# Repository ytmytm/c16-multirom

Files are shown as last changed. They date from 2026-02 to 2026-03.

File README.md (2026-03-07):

# C16 multirom




This project is a **multirom board for the Commodore 16 only**. It is heavily inspired by the [ROM update for Commodore 16](https://myoldcomputer.nl/other-computers/commodore-16/rom-update-commodore-16/) at My Old Computer.

The stock C16 uses **two separate chips** for BASIC and KERNAL. By putting **BASIC and KERNAL in a single 64K chip** (U3), we free the second socket for a **function ROM** (U4) e.g. 3-plus-1 and [Parobek](https://github.com/ytmytm/plus4-parobek), so the C16 gains capabilities similar to the Plus/4. Replacing the original mask ROMs with EEPROMs (e.g. 27E512) also reduces power draw.

**ROM switching**: each 64K chip holds two 32K images selected by address line A15. You can fix the choice with **switches** or **jumpers** on J1/J2 (closed = lower half, open = upper half), or add the optional **ATtiny85** to cycle through the four combinations with a long press on RESET.

## What you get

- **U3 (system ROM)**: One 64K chip with BASIC (same in both halves) and two kernals—e.g. stock in the lower 32K and JiffyDOS or 6510-patched in the upper 32K
- **U4 (function ROM)**: One 64K chip with **3-plus-1** in the lower 32K and **Parobek** in the upper 32K
- **Optional ATtiny85**: long-press RESET cycles U3 and U4 A15 through 00, 01, 10, 11 so you can change ROM set without opening the case or drilling holes for switches

## Hardware

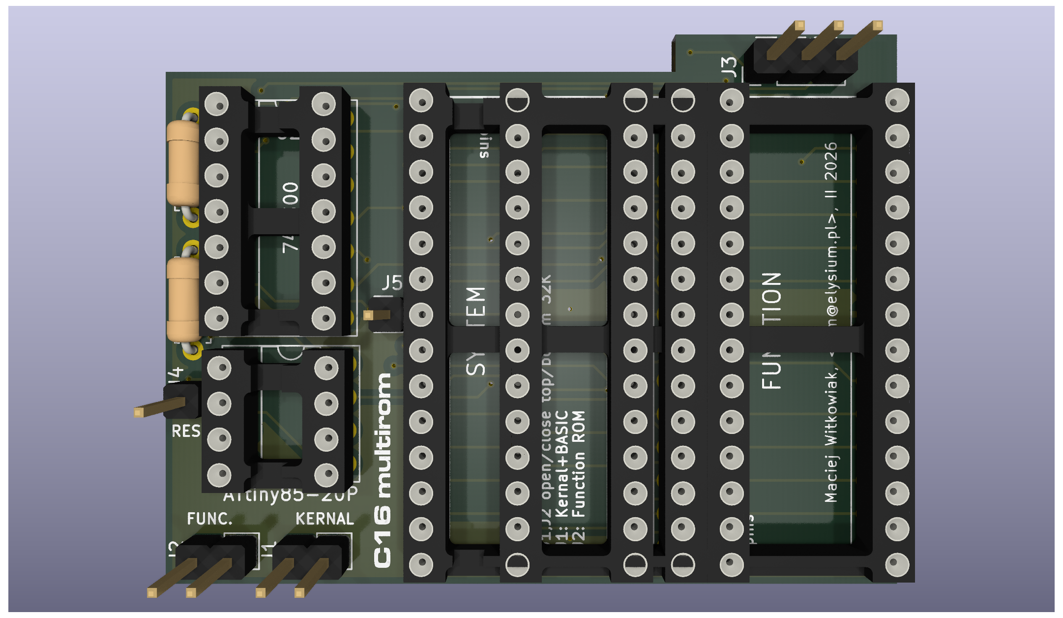
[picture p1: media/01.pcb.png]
Board


The board is designed for the **C16** only. It plugs into the original ROM sockets (system and function) and uses:

- **U3**: 27C512 / 27E512 (64K) — system ROM (BASIC + two kernals in one chip).
- **U4**: 27C512 / 27E512 (64K) — function ROM (3-plus-1 + Parobek).
- **Glue logic**: 74LS00 (or HC/HCT).
- **Optional**: ATtiny85-20P for RESET long-press bank switching.

Precision pin headers plug into the existing socket footprints. Jumpers J1 and J2 set A15 on U3 and U4 to choose the active 32K half; you can wire switches to J1/J2 instead, or let the ATtiny control them.

### BOM

- 2× 28-pin DIP socket (for 27C512/27E512)
- 1× 8-pin DIP socket (for ATtiny85, if used)
- 1× 74LS00 or 74HCT00
- 2× 10K resistors
- 2× 2-pin pinheaders (J1, J2 — ROM half select)
- 2x14 + 1x1 - precision pinheaders (round gold pins) for mainboard socket connection
- 2× 27C512 or 27E512 (64K EPROM/EEPROM)
- 1× ATtiny85-20P (optional, for long-press bank switch)

### Assembly

1. Solder the precision pin headers so the board mates with the original ROM sockets (U3 and U4 positions on the C16 mainboard). Check orientation.
2. Solder resistors, 74LS00, and sockets. If using the ATtiny, program it with the firmware in `attiny/` and fit it. **Note:** The ATtiny firmware is untested.
3. Burn the two 64K ROM images to the EPROMs (see **ROM images** below). Put the system ROM in the new U3 and the function ROM in the new U4 (note that their positions are reversed when compared to the mainboard).
4. Set J1 and J2 (or leave them open for default halves). Power on and test.

**Note on PLA replacements:** If you use PLA replacements (daughterboards with GAL or CPLD) that are wider than a 28-pin DIL chip, the extra width can make the multirom board a tight fit. After soldering the sockets—but before plugging in any chips—you may want to use sandpaper to remove some material from the right-hand edge of the PCB so it fits better.

There are no traces on that side; you can cut right up to the actual pins of the new U4 socket, leaving them open like half-circles.

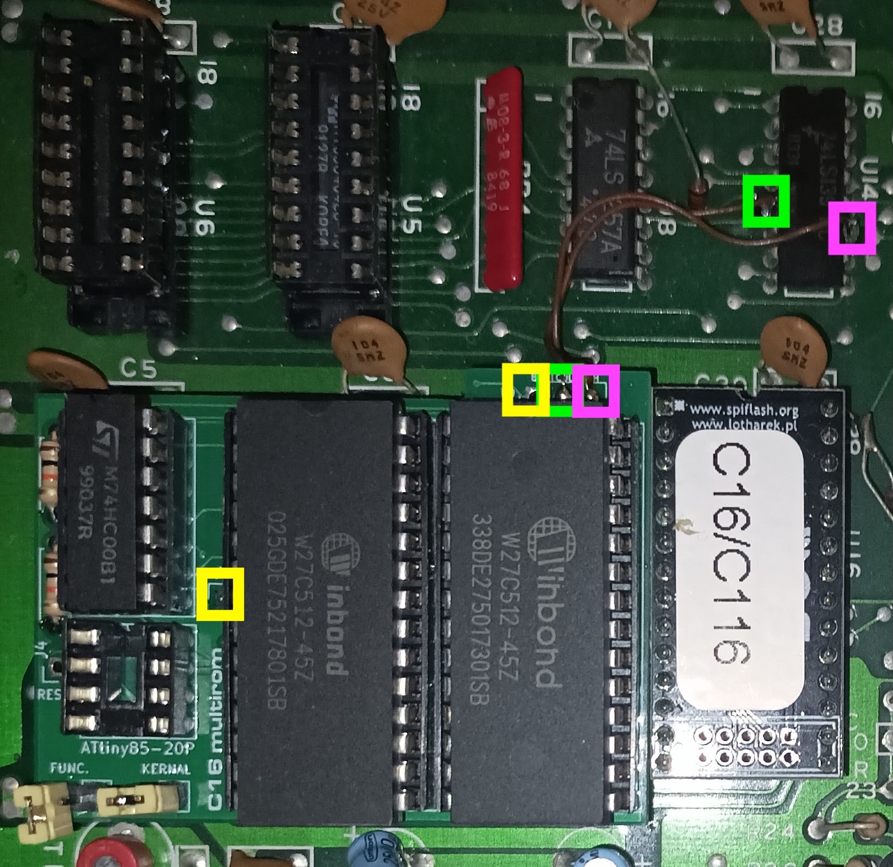
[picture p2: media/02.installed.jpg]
C16 multirom board installed in mainboard


*In the photo: the yellow square marks the /BASIC line, which is not connected on J3 because J5 takes it from the mainboard socket (U3 pin 22). The green and purple rectangles show how the J3 /C0LOW and /C0HIGH lines are taken from U14 pins 5 and 11.*

## Project files (KiCad)

- [KiCad project](kicad-c16-multirom/)
- [Schematic PDF](kicad-c16-multirom/plots/kicad-c16-multirom.pdf)
- [Gerbers](kicad-c16-multirom/gerbers/) (or use the packaged zip in that folder for JLCPCB etc.)
  <!-- Order boards: <a href="https://www.pcbway.com/project/shareproject/...">PCBWay</a> -->
- [docs/](docs/) — additional documentation and notes.

## ROM images

The `rom/` directory contains a script and Makefile that build the 64K ROM images from public sources (Zimmers, Parobek, 6510 kernals). Downloads are done once; you choose PAL/NTSC and which kernals go in the lower and upper half of U3.

**Pre-built images** (built from this repo and published in the **Releases** section) are:

- **System ROM (PAL)** — BASIC + stock kernal in lower half, 6510-patched kernal in upper half. For U3; use when J1 is closed = stock, open = 6510.
- **System ROM (NTSC)** — Same layout for NTSC.
- **Function ROM** — 3-plus-1 in lower 32K, Parobek in upper 32K. Single image for U4; J2 closed = 3-plus-1, open = Parobek.

So you can burn one system ROM per region (PAL and NTSC) and one function ROM, and use jumpers or the ATtiny to switch.

### Building the ROMs yourself

From the `rom/` directory:

```sh
cd rom
make
```

Interactive mode will ask for TV standard (PAL/NTSC) and which kernal to use for the lower and upper half of U3 (stock, JiffyDOS, or 6510-patched). Default is stock in the lower half and JiffyDOS in the upper; 6510 kernals are downloaded automatically from hackjunk.com. JiffyDOS binaries (not redistributable) go in `rom/sources/jiffydos/`; see `rom/sources/jiffydos/README.txt`.

Non-interactive example (stock lower, JiffyDOS upper, PAL):

```sh
./build.sh --pal --kernal-lower=stock --kernal-upper=jiffydos
```

Outputs are `rom/out/u3-system.rom` and `rom/out/u4-function.rom`.

To build the **release** variants (stock+6510 PAL, stock+6510 NTSC, and the single function ROM):

```sh
make build-ni PAL=1 KERNAL_LOWER=stock KERNAL_UPPER=6510   # PAL system ROM
make build-ni PAL=0 KERNAL_LOWER=stock KERNAL_UPPER=6510   # NTSC system ROM
# Function ROM is always 3-plus-1 + Parobek (one image)
```

Then copy `out/u3-system.rom` and `out/u4-function.rom` to your release assets.

## Related

- [ROM update for Commodore 16](https://myoldcomputer.nl/other-computers/commodore-16/rom-update-commodore-16/) (My Old Computer) — main inspiration for this project.
- [Parobek ROM](https://github.com/ytmytm/plus4-parobek) — Function ROM with fast loader and extras for C16/+4; the upper half of U4 on this board holds Parobek.
- [C16 / Plus/4 — 8501 to 6510 CPU conversion](https://hackjunk.com/2017/06/23/commodore-16-plus-4-8501-to-6510-cpu-conversion/) — 6510-patched kernals (used in the release ROM builds) come from this project.
- [CBM firmware (Zimmers.net)](https://www.zimmers.net/anonftp/pub/cbm/firmware/computers/plus4/) — Stock BASIC, KERNAL, and 3-plus-1 ROM images; the `rom/` build script downloads from here.

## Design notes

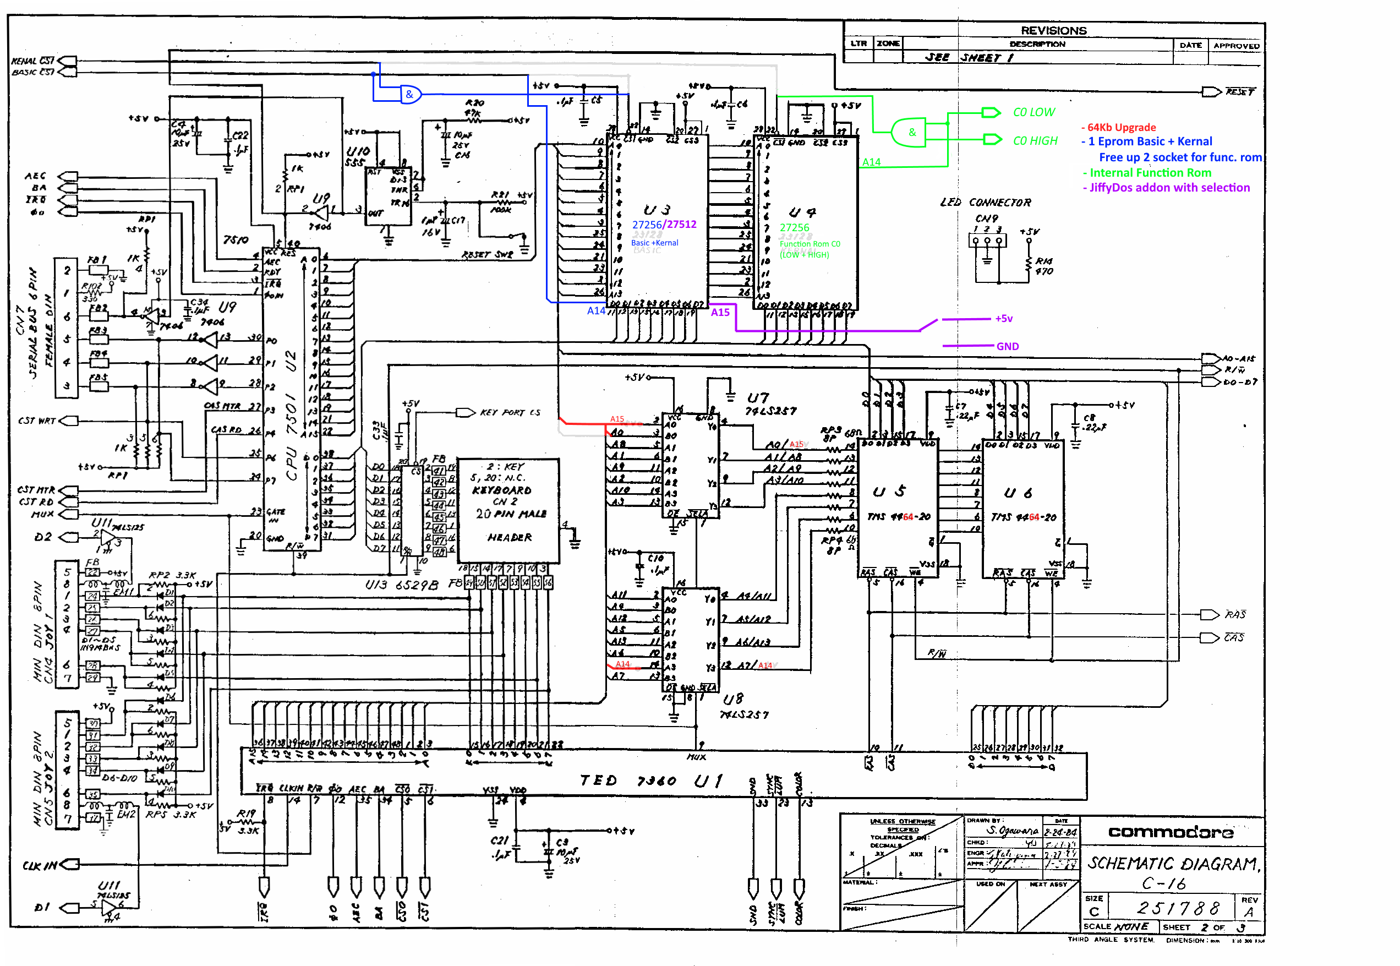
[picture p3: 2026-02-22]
docs/c16-251788-2of3_mods.png

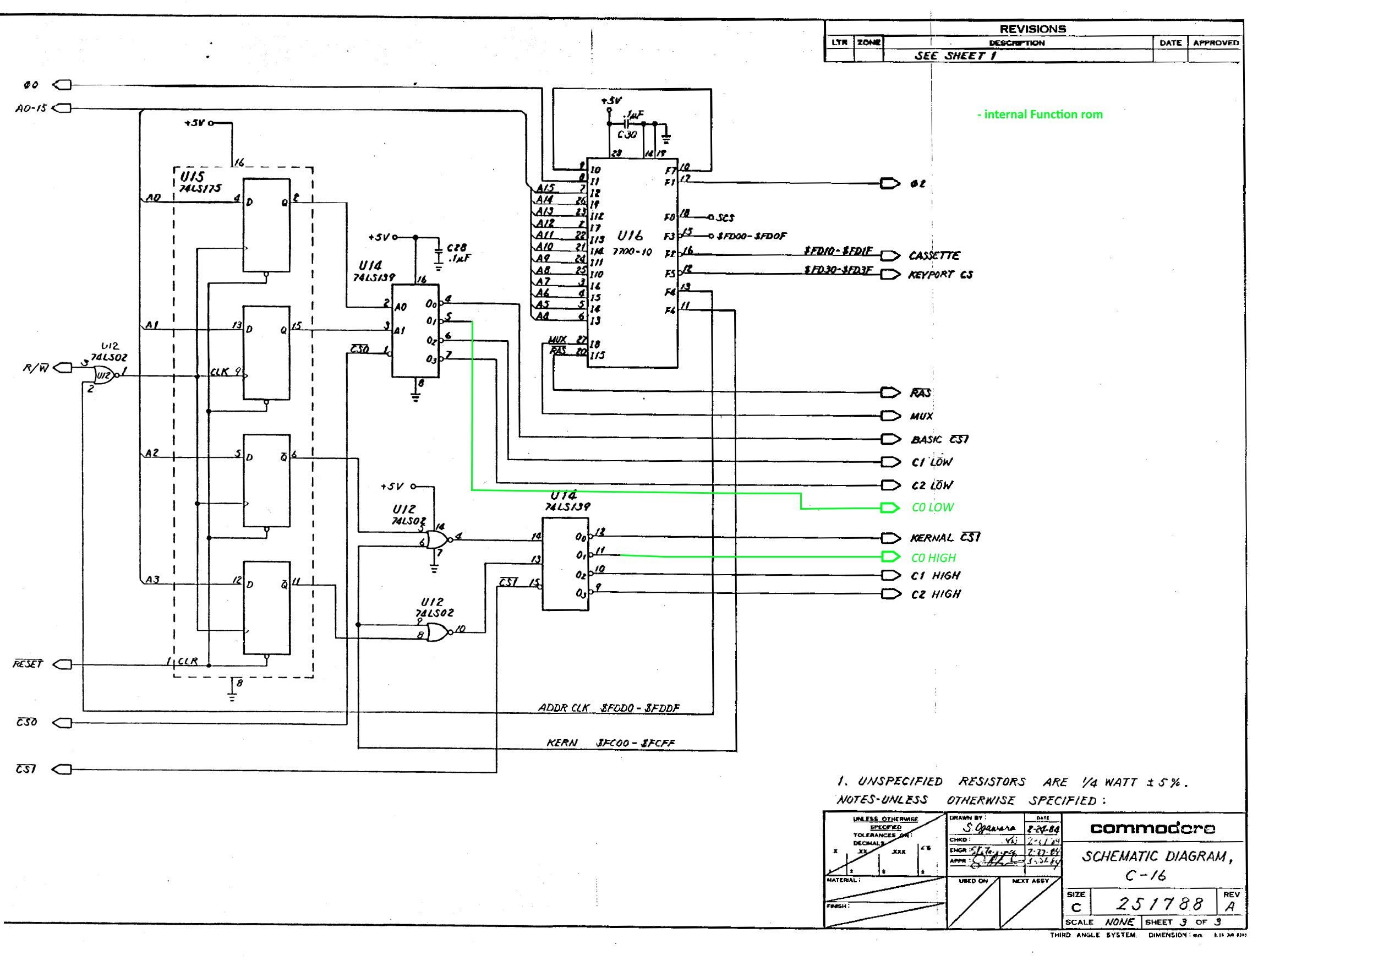
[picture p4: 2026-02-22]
docs/c16-251788-3of3_mods.png

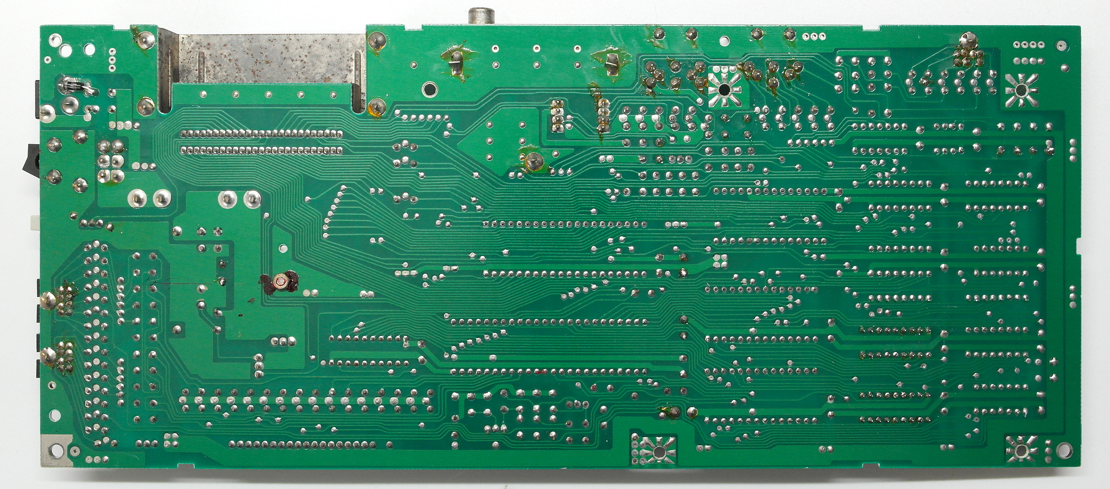
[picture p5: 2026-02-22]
docs/C16_PCBB.jpg

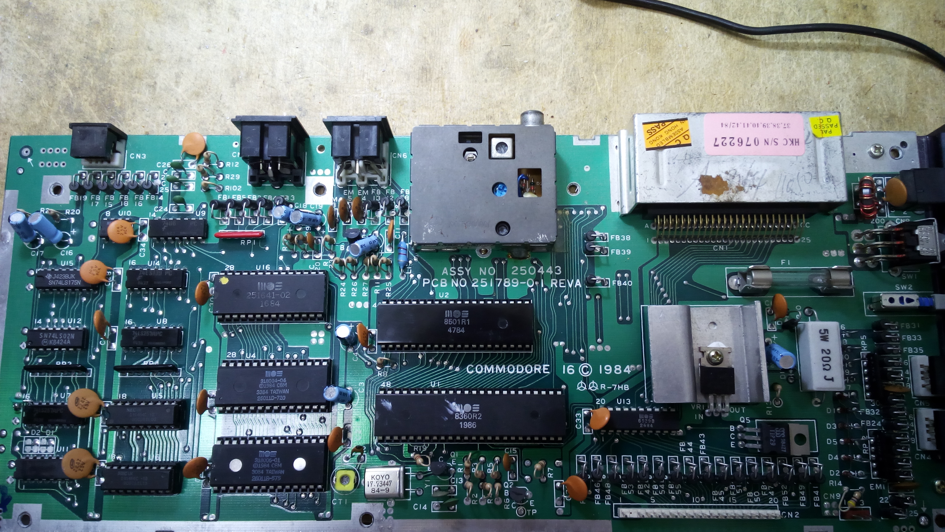
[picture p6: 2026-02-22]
docs/c16.jpg

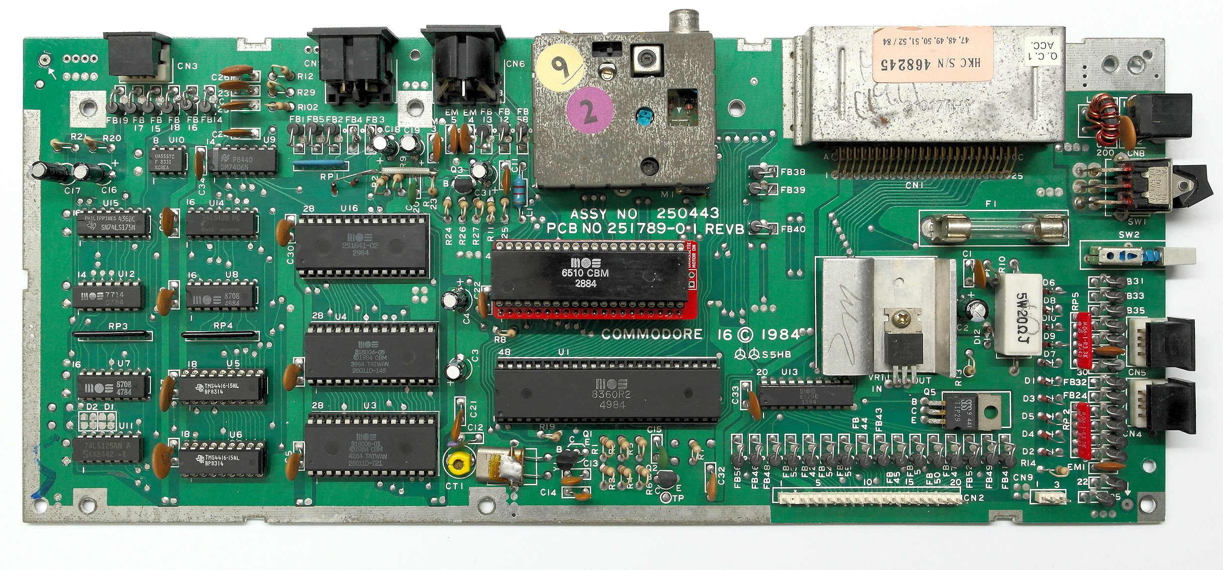
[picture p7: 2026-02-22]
docs/C16_PCBF.jpg

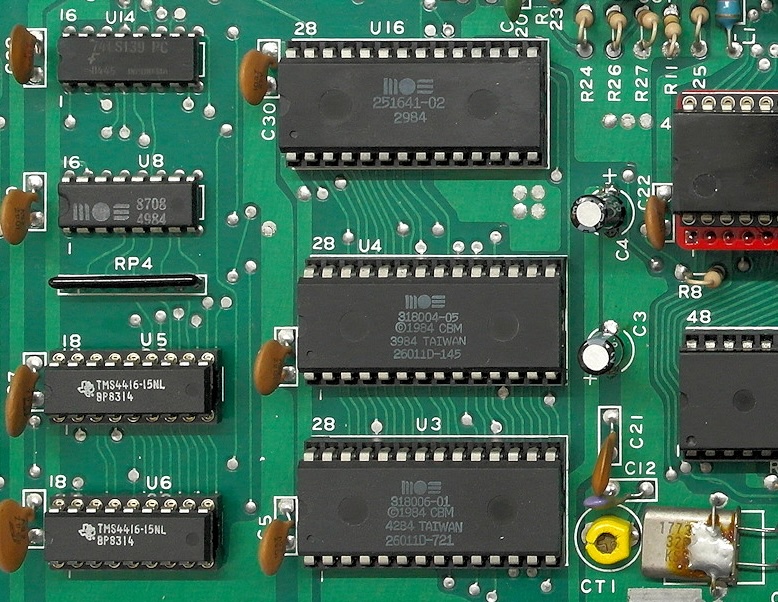
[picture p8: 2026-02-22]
kicad-c16-multirom/c16mobo.jpg

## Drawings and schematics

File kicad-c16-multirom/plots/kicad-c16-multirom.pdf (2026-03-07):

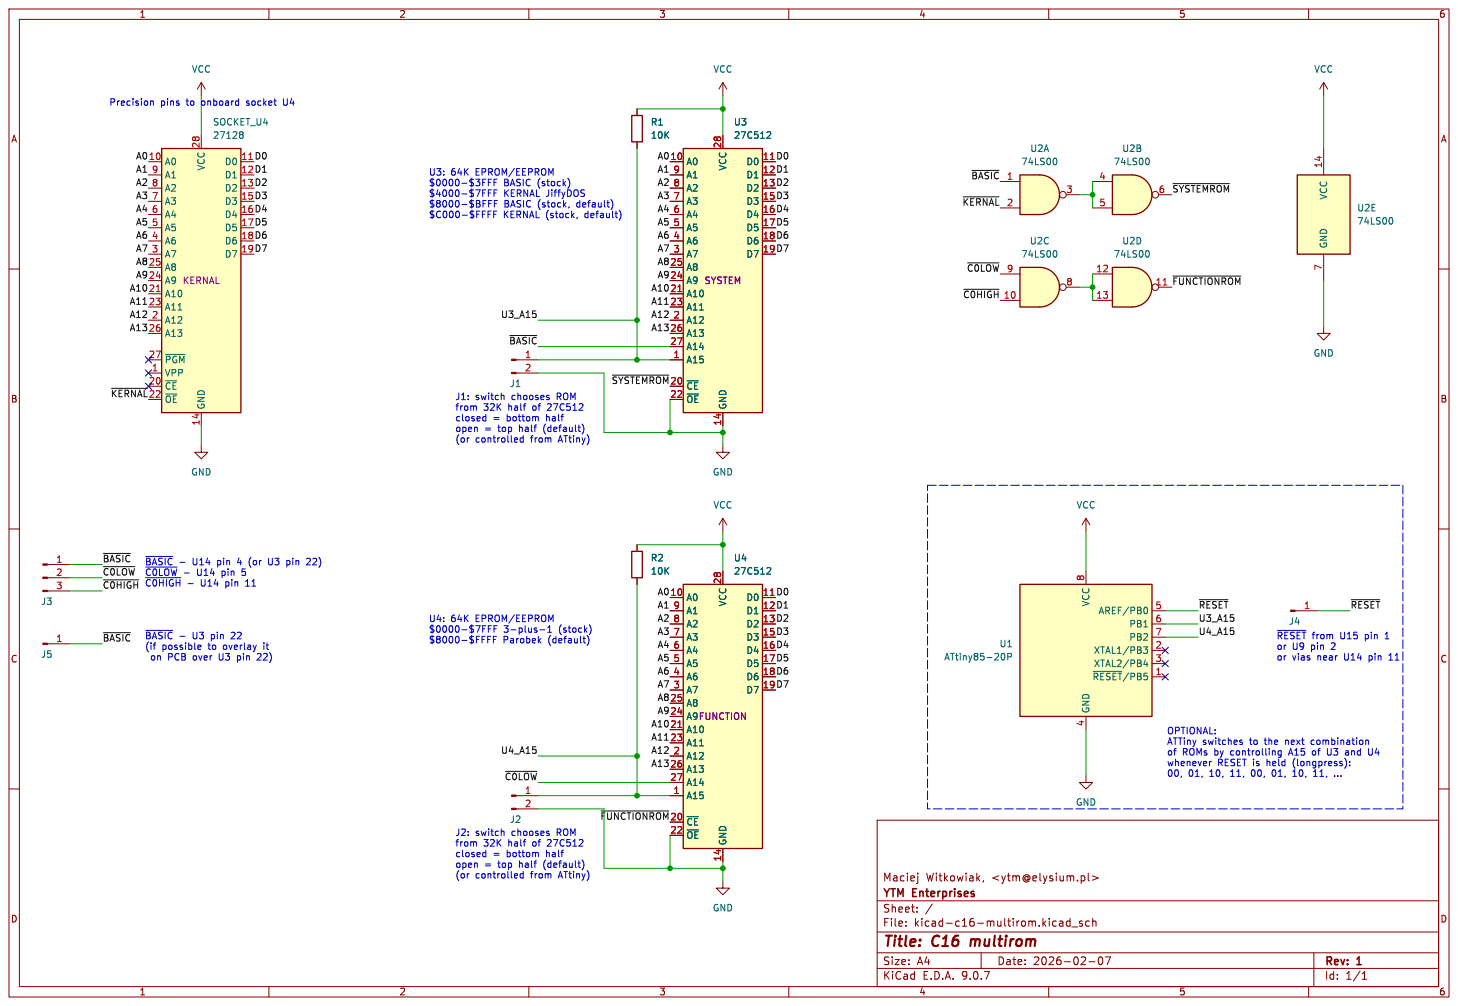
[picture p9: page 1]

J1: switch chooses ROM
from 32K half of 27C512
closed = bottom half open = top half (default)

~{BASIC}- U14 pin 4 (or U3 pin 22)
~{C0LOW}- U14 pin 5 ~{C0HIGH}- U14 pin 11 ~{BASIC}- U3 pin 22

or U9 pin 2
or vias near U14 pin 11

J2: switch chooses ROM

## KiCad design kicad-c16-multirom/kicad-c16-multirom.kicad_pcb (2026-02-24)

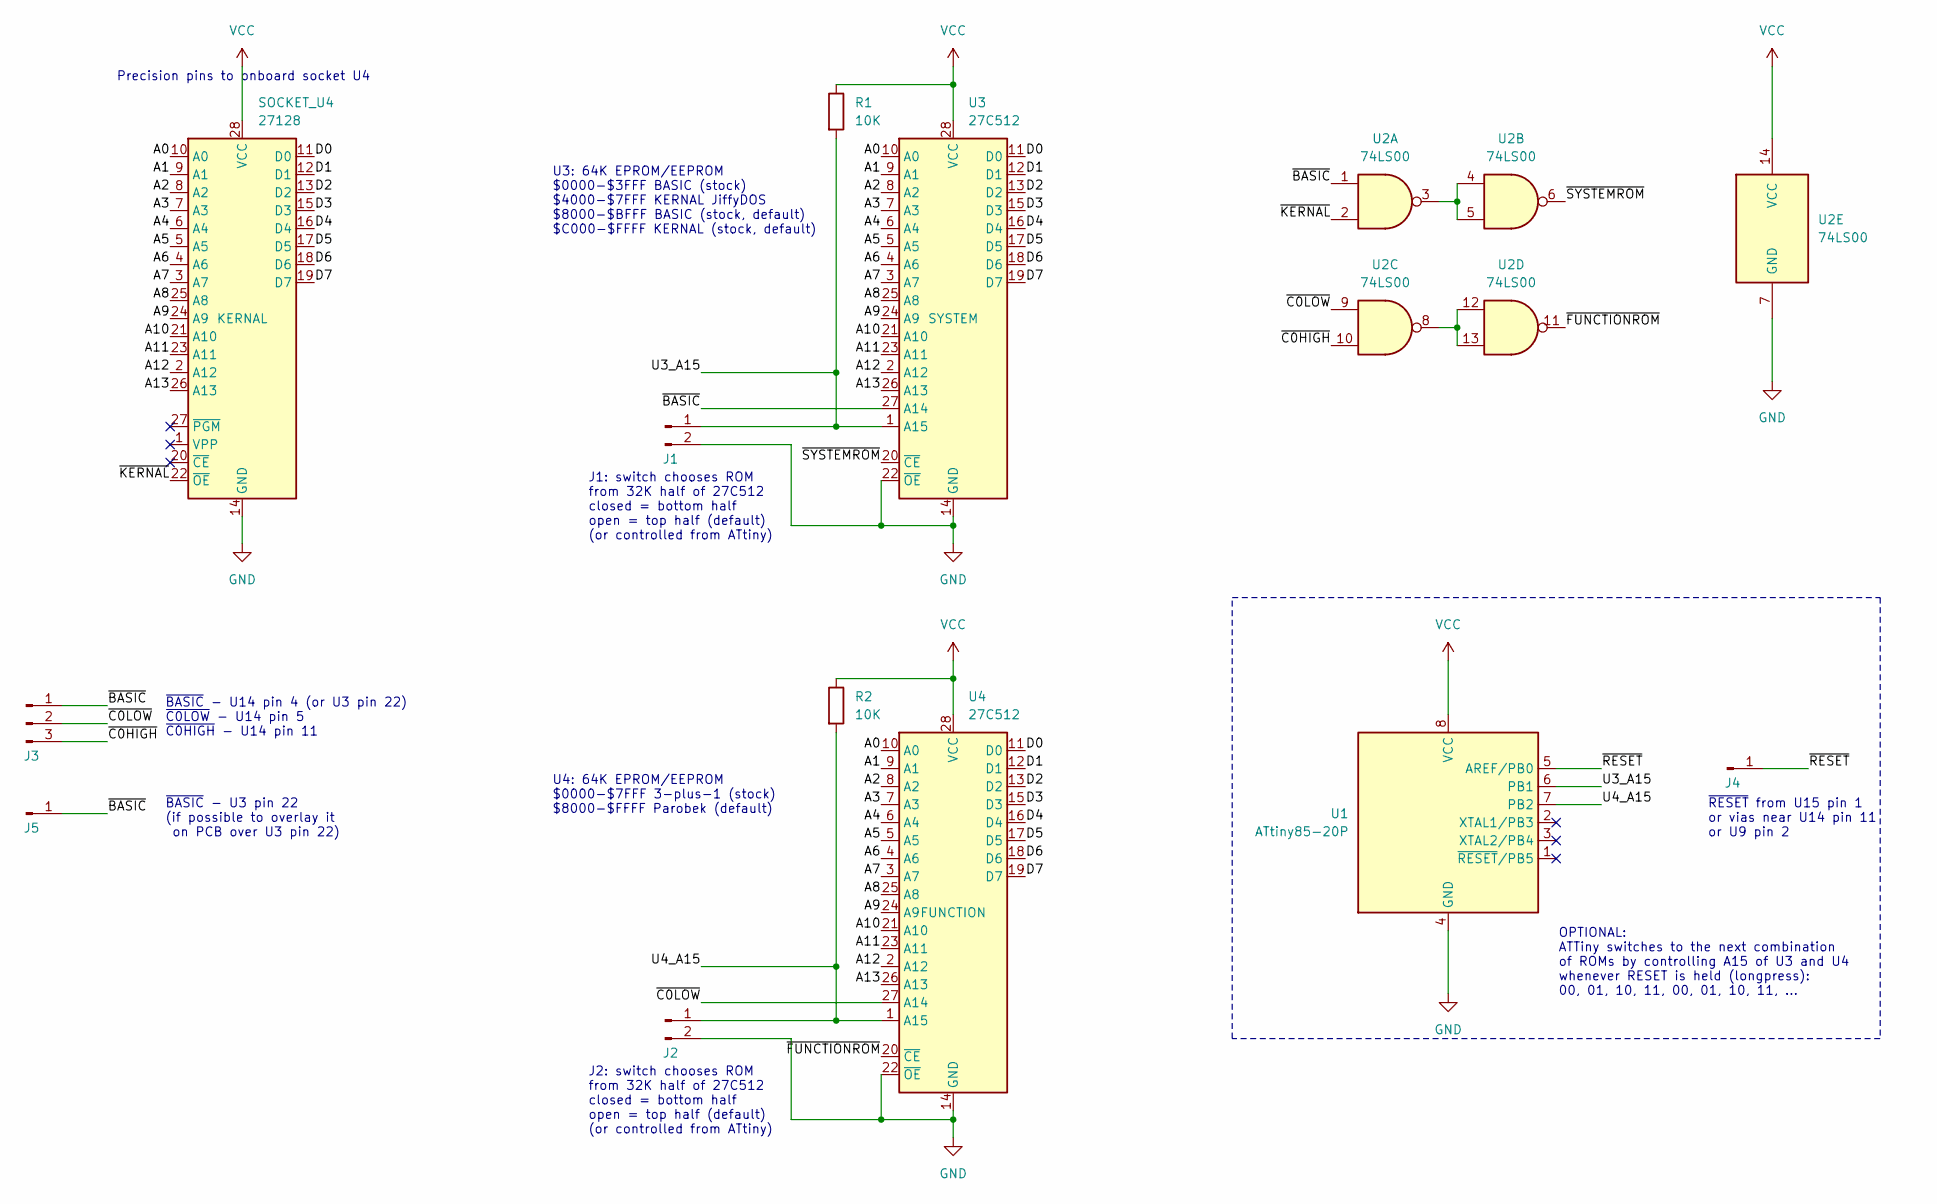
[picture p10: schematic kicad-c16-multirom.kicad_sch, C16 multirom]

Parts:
J1, J2: Conn_01x02_Pin; PinHeader_1x02_P2.54mm_Vertical
J3: Conn_01x01_Pin; PinHeader_1x03_P2.54mm_Vertical
J4, J5: Conn_01x01_Pin; PinHeader_1x01_P2.54mm_Vertical
R1, R2: 10K; R_Axial_DIN0207_L6.3mm_D2.5mm_P7.62mm_Horizontal
SOCKET_U4: 27128; DIP-28_W15.24mm_Socket
U1: ATtiny85-20P; DIP-8_W7.62mm_Socket_LongPads
U2: 74LS00; DIP-14_W7.62mm_Socket_LongPads
U3, U4: 27C512; DIP-28_W15.24mm_Socket_LongPads

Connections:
/A0: SOCKET_U4.10 (A0), U3.10 (A0), U4.10 (A0)
/A1: SOCKET_U4.9 (A1), U3.9 (A1), U4.9 (A1)
/A2: SOCKET_U4.8 (A2), U3.8 (A2), U4.8 (A2)
/A3: SOCKET_U4.7 (A3), U3.7 (A3), U4.7 (A3)
/A4: SOCKET_U4.6 (A4), U3.6 (A4), U4.6 (A4)
/A5: SOCKET_U4.5 (A5), U3.5 (A5), U4.5 (A5)
/A6: SOCKET_U4.4 (A6), U3.4 (A6), U4.4 (A6)
/A7: SOCKET_U4.3 (A7), U3.3 (A7), U4.3 (A7)
/A8: SOCKET_U4.25 (A8), U3.25 (A8), U4.25 (A8)
/A9: SOCKET_U4.24 (A9), U3.24 (A9), U4.24 (A9)
/A10: SOCKET_U4.21 (A10), U3.21 (A10), U4.21 (A10)
/A11: SOCKET_U4.23 (A11), U3.23 (A11), U4.23 (A11)
/A12: SOCKET_U4.2 (A12), U3.2 (A12), U4.2 (A12)
/A13: SOCKET_U4.26 (A13), U3.26 (A13), U4.26 (A13)
/D0: SOCKET_U4.11 (D0), U3.11 (D0), U4.11 (D0)
/D1: SOCKET_U4.12 (D1), U3.12 (D1), U4.12 (D1)
/D2: SOCKET_U4.13 (D2), U3.13 (D2), U4.13 (D2)
/D3: SOCKET_U4.15 (D3), U3.15 (D3), U4.15 (D3)
/D4: SOCKET_U4.16 (D4), U3.16 (D4), U4.16 (D4)
/D5: SOCKET_U4.17 (D5), U3.17 (D5), U4.17 (D5)
/D6: SOCKET_U4.18 (D6), U3.18 (D6), U4.18 (D6)
/D7: SOCKET_U4.19 (D7), U3.19 (D7), U4.19 (D7)
/U3_A15: J1.1, R1.2, U1.6 (PB1), U3.1 (A15)
/U4_A15: J2.1, R2.2, U1.7 (PB2), U4.1 (A15)
/~BASIC: J3.1, J5.1, U2.1, U3.27 (A14)
/~C0HIGH: J3.3, U2.10
/~C0LOW: J3.2, U2.9, U4.27 (A14)
/~FUNCTIONROM: U2.11, U4.20 (~CE)
/~KERNAL: SOCKET_U4.22 (~OE), U2.2
/~RESET: J4.1, U1.5 (AREF/PB0)
/~SYSTEMROM: U2.6, U3.20 (~CE)
GND: J1.2, J2.2, SOCKET_U4.14 (GND), U1.4 (GND), U2.7 (GND), U3.14 (GND), U3.22 (~OE), U4.14 (GND), U4.22 (~OE)
unnamed: U2.3, U2.4, U2.5
unnamed: U2.8, U2.12, U2.13
VCC: R1.1, R2.1, SOCKET_U4.28 (VCC), U1.8 (VCC), U2.14 (VCC), U3.28 (VCC), U4.28 (VCC)

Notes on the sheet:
~{RESET} from U15 pin 1 or vias near U14 pin 11 or U9 pin 2
U3: 64K EPROM/EEPROM $0000-$3FFF BASIC (stock) $4000-$7FFF KERNAL JiffyDOS $8000-$BFFF BASIC (stock, default) $C000-$FFFF KERNAL (stock, default)
U4: 64K EPROM/EEPROM $0000-$7FFF 3-plus-1 (stock) $8000-$FFFF Parobek (default)
Precision pins to onboard socket U4
~{BASIC} - U3 pin 22 (if possible to overlay it on PCB over U3 pin 22)
J2: switch chooses ROM from 32K half of 27C512 closed = bottom half open = top half (default) (or controlled from ATtiny)
J1: switch chooses ROM from 32K half of 27C512 closed = bottom half open = top half (default) (or controlled from ATtiny)
OPTIONAL: ATTiny switches to the next combination of ROMs by controlling A15 of U3 and U4 whenever RESET is held (longpress): 00, 01, 10, 11, 00, 01, 10, 11, ...
~{BASIC} - U14 pin 4 (or U3 pin 22) ~{C0LOW} - U14 pin 5 ~{C0HIGH} - U14 pin 11

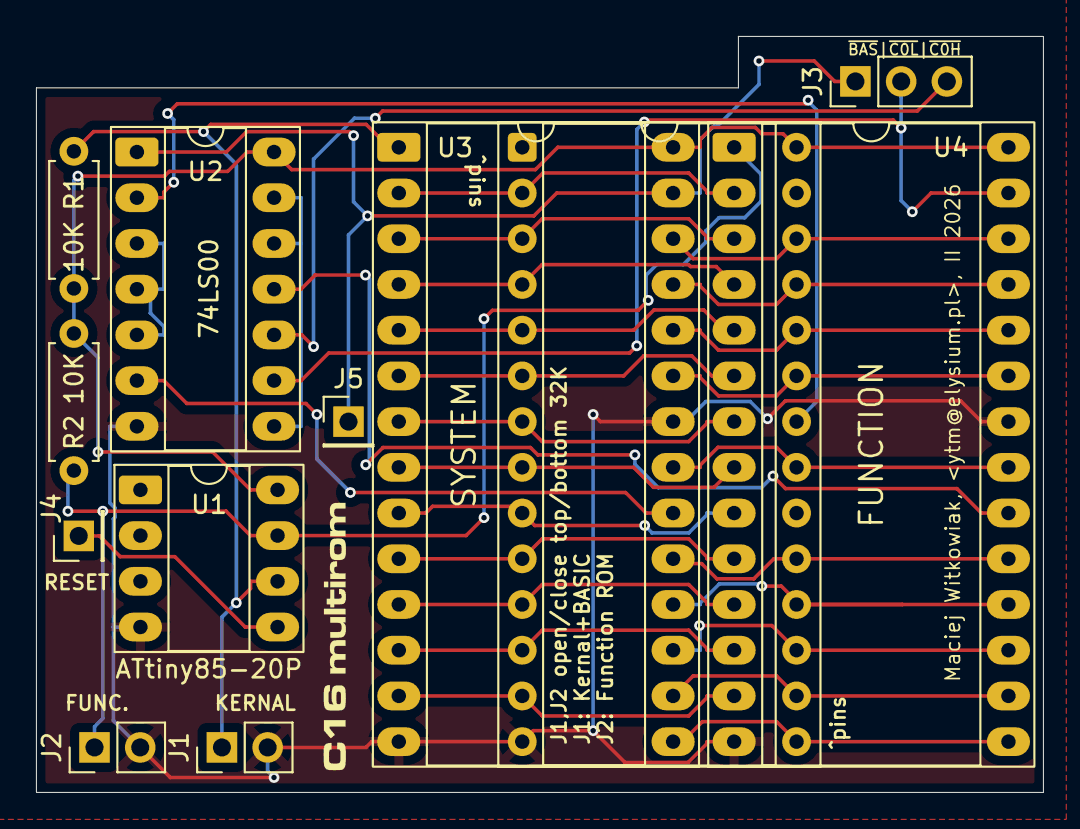
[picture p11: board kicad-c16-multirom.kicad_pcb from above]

Board: 2 copper layers, 55.9 x 42.0 mm, 13 parts (0 on the bottom side), 35 nets.

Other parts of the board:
kibuzzard-6987CFF9: G***; kibuzzard-6987CFF9

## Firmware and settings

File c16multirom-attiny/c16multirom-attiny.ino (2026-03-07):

// IDE: ATtiny25/45/85, internal 1MHz
// 1MHz is the default speed, no need to switch fuses to 8MHz
// compile to HEX (Sketch->Export compiled binary) and burn using TL866-II
//
// ROM bank switcher: detects long presses on system /RESET line,
// cycles through 4 banks (00 -> 01 -> 10 -> 11 -> 00 ...) on two output pins.
// Normal/short resets are ignored. State resets to 00 on every power-on.

// pinout
//   /RESET 1  U  8 VCC
//   A3/PB3 2     7 PB2 --> output: bank address A1 (MSB)
//   A2/PB4 3     6 PB1 --> output: bank address A0 (LSB)
//      GND 4     5 PB0 <-- input: system /RESET (active low)

#define LONG_PRESS_MS  600
#define DEBOUNCE_MS    50

const uint8_t pin_A0    = 1; // PB1, pin 6 -- bank address bit 1
const uint8_t pin_A1    = 2; // PB2, pin 7 -- system /RESET sense
const uint8_t pin_reset = 0; // PB0, pin 5 -- bank address bit 0

uint8_t bank = 0;

static void applyBank() {
  digitalWrite(pin_A0, bank & 1);
  digitalWrite(pin_A1, (bank >> 1) & 1);
}

void setup() {
  pinMode(pin_A0, OUTPUT);
  pinMode(pin_A1, OUTPUT);
  applyBank();

  pinMode(pin_reset, INPUT_PULLUP);

  // Wait for the system to release /RESET after power-on.
  // This avoids treating the power-on reset as a long press.
  while (digitalRead(pin_reset) == LOW)
    ;
  delay(DEBOUNCE_MS);
}

void loop() {
  // Wait for /RESET to be asserted (pulled LOW)
  if (digitalRead(pin_reset) != LOW)
    return;

  delay(DEBOUNCE_MS);
  if (digitalRead(pin_reset) != LOW)
    return;

  // /RESET is confirmed LOW -- start timing
  unsigned long pressed_at = millis();

  while (digitalRead(pin_reset) == LOW) {
    if (millis() - pressed_at >= LONG_PRESS_MS) {
      // Long press detected -- advance bank while system is held in reset
      bank = (bank + 1) & 3;
      applyBank();

      // Wait for button release
      while (digitalRead(pin_reset) == LOW)
        ;
      delay(DEBOUNCE_MS);
      return;
    }
  }
  // /RESET released before threshold -- short press, ignore
  delay(DEBOUNCE_MS);
}

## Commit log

2026-02-24 correct reference image placement, lock footprints for precision pins that go down to the mainboard
    [kicad-c16-multirom.kicad_pcb]
2026-02-24 Update README with PLA replacement note and add PCB reference image
2026-03-07 ATTiny code updated and tested, clarified on schematics how to connect /RESET line
    [kicad-c16-multirom.kicad_sch]
